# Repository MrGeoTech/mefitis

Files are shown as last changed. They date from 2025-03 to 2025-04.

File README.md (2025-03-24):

# Mefitis

The sensor data gathering and presenting software suite for NDSU's Bison Pullers. Named after the 
roman goddess of poisonous gasses, this platform allows us to measure sensors all over the tractor.
We use this data to improve many aspects of the tractor, including emissions and noise.

## Database Design

Database name: `data`  
Each row represents one seconds worth of data. The columns are for each different sensor.

The current sensors are as follows:  
`Sound_Engine`, `Sound_Operator`, `Emissions_Engine`, `Emissions_Operator`, `Temp_Engine`, `Temp_Exhaust`, `RPM`

## Arduino Uno 3

#### Installing

Pre-req: `arduino-cli`

You can either install the software from the pi or from any other computer. Start by going into the
`arduino` directory.

Next, compile and upload the code:

```bash
sudo arduino-cli compile --fqbn arduino:avr:uno arduino.ino
sudo arduino-cli upload -p /dev/ttyACM0 --fqbn arduino:avr:uno arduino.ino
```

Now simply plug in the arduino to the pi, start the webserver, and everything should be working.

## Raspberry Pi

#### Installation

To install of a raspberry pi, first, install Raspbian Minimal 64-bit OS onto the SD card. Make sure that the username
is `pullers`.

Next, make sure to update the system and then install `git` and `postgresql`.

```bash
sudo apt update
sudo apt upgrade
sudo apt install -y git postgresql libpg-dev
sudo apt autoremove
```

Next, configure `postgresql` by running `sudo -u postgres psql`. This should take you to a SQL shell.
To configure from there, first create a new database called `data`.

```sql
CREATE TABLE IF NOT EXISTS data (id SERIAL PRIMARY KEY, Sound_Engine REAL, Sound_Operator REAL, Emissions_Engine REAL, Emissions_Operator REAL, Temp_Engine REAL, Temp_Exhaust REAL, RPM INTEGER);
```

Then set the postgres user password.

```sql
ALTER USER postgres with encrypted password 'postgres';
```

You should now be able to exit the SQL shell. Next, setup configure git with whatever username and 
email you want. Now, you will have to install nix. To do this, simply run `sh <(curl -L https://nixos.org/nix/install) --daemon`.
You should be able to just follow the prompts and it should install nicely.

After installing nix, restart the system.

Now, download the git repo into the home folder using `git clone https://github.com/MrGeoTech/mefitis.git`.

Finally, setup a python venv at `~/venv`. Make sure to add the following python packages:
`w1thermsensor[async] pyserial psycopg2 gpiozero RPi.GPIO`

#### Running

To run the program on the pi, first go into the `pi` directory and run `nix-shell`. This should
setup the environment to run the server in. Next, just run `sh ./run.sh` and everything should start.

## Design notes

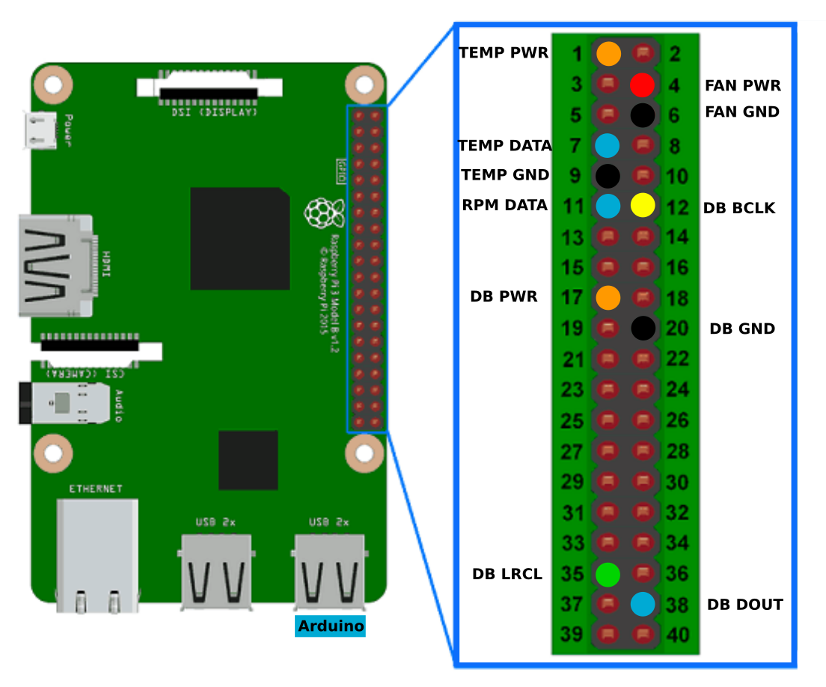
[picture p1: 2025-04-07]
pi/PinConnections.png

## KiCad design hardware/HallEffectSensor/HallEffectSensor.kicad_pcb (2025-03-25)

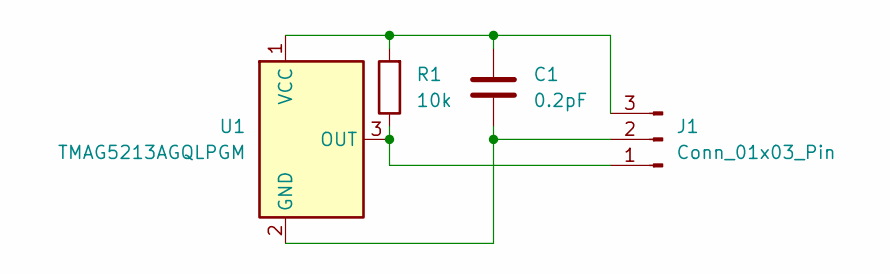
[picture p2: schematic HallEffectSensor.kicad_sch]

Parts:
C1: 0.2pF; C_0402_1005Metric
J1: Conn_01x03_Pin; PinHeader_1x03_P2.54mm_Horizontal
R1: 10k; R_0603_1608Metric
U1: TMAG5213AGQLPGM; TO-92_Inline

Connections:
unnamed: J1.1, R1.1, U1.3 (OUT)
unnamed: C1.2, J1.2, U1.2 (GND)
unnamed: C1.1, J1.3, R1.2, U1.1 (VCC)

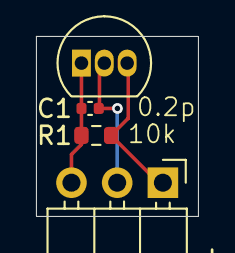
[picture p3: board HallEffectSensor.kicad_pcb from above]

Board: 2 copper layers, 9.0 x 10.0 mm, 4 parts (0 on the bottom side), 3 nets.

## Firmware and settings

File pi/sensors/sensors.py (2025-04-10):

from gpiozero import Button
from math import log10
from w1thermsensor import AsyncW1ThermSensor, Unit

import RPi.GPIO as GPIO
import asyncio
import numpy as np
import psycopg2
import pyaudio
import serial as s
import statistics
import time

# PostgreSQL Database Configuration
DB_CONFIG = {
    "dbname": "data",
    "user": "postgres",
    "password": "postgres",
    "host": "localhost",
    "port": 5432
}

# Constants
MICROSECONDS_PER_MINUTE = 60 * 1000 * 1000

# Sensors should be wired as following:
# TOP    -> GPIO 17 (PIN 11)
# RIGHT  -> GPIO 27 (PIN 13)
# BOTTOM -> GPIO 22 (PIN 15)
# LEFT   -> GPIO 23 (PIN 16)
SENSORS = {
    "TOP": Button(17),
    #"RIGHT": Button(27),
    #"BOTTOM": Button(22),
    #"LEFT": Button(23)
}

temp_data = [0, 0]
last_time = None
rpm = 0

p = pyaudio.PyAudio()
WIDTH = 2
CHANNELS = 2
RATE = int(p.get_default_input_device_info()['defaultSampleRate'])
DEVICE = p.get_default_input_device_info()['index']
db_correction = 65.0

accum_left = []
accum_right = []

def callback(in_data, frame_count, time_info, status):
    global accum_left, accum_right
    # Split stereo data into left and right mono streams
    
    audio_data = np.frombuffer(in_data, dtype=np.int16)
    audio_float = audio_data.astype(np.float32) / 32767

    # Split stereo data into left and right channels
    left = audio_float[::2]
    right = audio_float[1::2]

    # Append DB to global list
    accum_left.extend(left)
    accum_right.extend(right)

    return in_data, pyaudio.paContinue

def calculate_rpm():
    global last_time
    global rpm
    current_time = int(time.time_ns() / 1000)
    
    if last_time is not None:
        time_diff = current_time - last_time
        if time_diff >= 10: # Debouncing
            rpm = (MICROSECONDS_PER_MINUTE / time_diff) / len(SENSORS) # Convert to RPM
        else:
            return # Keep last_time the same
    
    last_time = current_time

def init_db():
    """Initialize the PostgreSQL database and create the necessary table if it doesn't exist."""
    try:
        conn = psycopg2.connect(**DB_CONFIG)
        cursor = conn.cursor()
        cursor.execute("""
        CREATE TABLE IF NOT EXISTS data (
            id SERIAL PRIMARY KEY,
            Sound_Engine REAL,
            Sound_Operator REAL,
            Emissions_Engine REAL,
            Emissions_Operator REAL,
            Temp_Engine REAL,
            Temp_Exhaust REAL,
            RPM INTEGER
        )
        """)
        conn.commit()
        cursor.close()
        conn.close()
    except psycopg2.Error as e:
        print(f"Database initialization error: {e}")

def save_to_db(data):
    """Save aggregated data to the PostgreSQL database."""
    try:
        conn = psycopg2.connect(**DB_CONFIG)
        cursor = conn.cursor()
        cursor.execute("""
            INSERT INTO data (Sound_Engine, Sound_Operator, Emissions_Engine, Emissions_Operator, Temp_Engine, Temp_Exhaust, RPM)
            VALUES (%s, %s, %s, %s, %s, %s, %s)
        """, data)
        conn.commit()
        cursor.close()
        conn.close()
    except psycopg2.Error as e:
        print(f"Database insert error: {e}")

async def update_temp_data():
    """Asynchronously update global temperature data."""
    global temp_data
    sensors = AsyncW1ThermSensor.get_available_sensors()
    while True:
        new_temp_data = temp_data.copy()  # Keep previous values in case of error
        for i, sensor in enumerate(sensors):
            try:
                temp = await sensor.get_temperature(Unit.DEGREES_C)
                new_temp_data[i] = temp
            except Exception as e:
                print(f"Temp Sensor Error: {e}")
        temp_data = new_temp_data
        await asyncio.sleep(1)

def get_arduino_data(serial):
    """Read a line from the Arduino and parse it into a list of integers."""
    serial.write(b'\x00')
    data = serial.readline().strip()
    
    if len(data) % 2 != 0:
        return []

    int_list = []
    for i in range(0, len(data), 2):
        high_byte = data[i]
        low_byte = data[i + 1]
        int_value = (high_byte << 8) | low_byte
        int_list.append(int_value)

    return int_list

def aggregate_data(sensor_buffer):
    """Compute the average of collected sensor data over the past second."""
    avg_data = [sum(col) / len(col) for col in zip(*sensor_buffer)]
    return avg_data

def get_average_db():
    global accum_left, accum_right

    if not accum_left or not accum_right:
        return [float('-inf'), float('-inf')]  # No audio data

    # Convert to NumPy arrays for efficient processing
    left_array = np.array(accum_left, dtype=np.float32)
    right_array = np.array(accum_right, dtype=np.float32)

    # Compute RMS
    rms_left = np.sqrt(np.mean(left_array ** 2))
    rms_right = np.sqrt(np.mean(right_array ** 2))

    # Convert RMS to decibels (as Python floats)
    #def rms_to_db(rms):
    #    return float(20 * np.log10(rms)) if rms > 0 else float('-inf')

    left_db = float(rms_left)
    right_db = float(rms_right)

    # Clear the accumulators
    accum_left = []
    accum_right = []

    return [left_db, right_db]

async def main():
    try:
        init_db()

        GPIO.setmode(GPIO.BCM)
        GPIO.setup(4, GPIO.IN, pull_up_down=GPIO.PUD_UP)

        # Attach the same event handler to all sensors
        for sensor in SENSORS.values():
            sensor.when_pressed = calculate_rpm

        # Initialize Serial Connection
        #serial = s.Serial('/dev/ttyACM0', baudrate=19200, timeout=1)
        
        asyncio.create_task(update_temp_data())
        
        sensor_buffer = []  # Store 100 readings (10ms * 100 = 1s)
        iterations = 0

        print(p.get_default_input_device_info())
        stream = p.open(format=p.get_format_from_width(WIDTH),
                        input_device_index=DEVICE,
                        channels=CHANNELS,
                        rate=RATE,
                        input=True,
                        output=False,
                        stream_callback=callback)
        
        stream.start_stream()
        
        while True:
            try:
                arduino_data = [0,0,0,0]#get_arduino_data(serial)  # Returns a list [sensor1, sensor2, sensor3, ...]
                
                if len(temp_data) != 2 or len(arduino_data) != 4:
                    continue  # Skip iteration if data is incomplete

                sound_data = get_average_db()
                emissions_data = arduino_data[2:4]
                rpm_data = rpm  # Single integer

                # Collect sensor readings
                sensor_buffer.append(sound_data + emissions_data + temp_data + [rpm])

                # Check if 1 second has passed
                if iterations == 100:
                    if sensor_buffer:
                        # Aggregate and store in the database
                        aggregated = aggregate_data(sensor_buffer)
                        save_to_db(aggregated)

                        # Reset buffer
                        sensor_buffer = []
                        iterations = 0

                await asyncio.sleep(0.01)  # 10ms delay
                iterations += 1

            except Exception as e:
                print(f"Error: {e}")
    except Exception as e:
        print(f"Error: {e}")
    finally:
        if 'serial' in locals() and serial.is_open:
            serial.close()
        if 'stream' in locals() and stream.is_active():
            stream.stop_stream()
            stream.close()
        if 'p' in locals():
            p.terminate()

if __name__ == "__main__":
    asyncio.run(main())

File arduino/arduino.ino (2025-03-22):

const int sample_ports_length = 4;
const int sample_ports[] = { A0, A1, A2, A3 };

void setup() {
    Serial.begin(19200);
}

void loop() {
    if (Serial.read() == 0) {
        for (int i = 0; i < sample_ports_length; i++) {
            const int value = analogRead(sample_ports[i]);
            Serial.write(highByte(value));
            Serial.write(lowByte(value));
        }
        Serial.write('\n');
    }
}

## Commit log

2025-03-13 Change system to now work and delete irrelevant files
    [Recording-2025-03-11_23-39-40.csv, Recording-2025-03-11_23-41-25.csv]
2025-03-13 Update sensors
2025-03-13 More sensors.py changes
2025-03-13 Locking in baud rate and trying to make sensors.py work
2025-03-13 More updates to sensors
2025-03-13 Fix sensors
2025-03-14 Trying to fix not updating the databse
    [sensors.py]
2025-03-14 More print debugging
2025-03-14 Remove debugging prints
2025-03-22 Update test sensors
2025-03-22 Configure therm sensor connection
2025-03-24 Run sensors.py as root
2025-03-24 Made temp sensing more resiliant to failures
    [sensors.py]
2025-03-24 Add some print debugging
2025-03-24 Print debugging
2025-03-24 Update to be more resiliant to temp sensors failures
    [sensors.py]
2025-03-24 Uncomment arduino. Everything except for the RPM sensors has been tested and works
2025-03-24 Update sensors to convert sensor data to db
2025-03-25 Start working on pcb for hall-effect sensors
    [HallEffectSensor.kicad_pcb, HallEffectSensor.kicad_sch]
2025-03-27 Update sensors to use one sensor
2025-03-28 Switch to at least 10 us and use len(SENSORS)
2025-03-28 Remove Print
2025-03-28 Revert back to raw values. We'll just fix it in post
    [sensors.py, test_monitor.py]
2025-04-03 Update to test new sound sensors
2025-04-07 Add printing devices
2025-04-07 Update test_sensors with correct device index
    [test_sensors.py]
2025-04-07 Remove prints
2025-04-07 Update sensors to use new sound sensors
2025-04-09 Go back to default frames per buffer
2025-04-10 Change calibration method
2025-04-10 Do python correctly..I think..
    [sensors.py]
2025-04-10 Test calibrations
